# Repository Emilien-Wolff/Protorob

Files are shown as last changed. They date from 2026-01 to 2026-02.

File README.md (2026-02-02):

# Protorob – Robot thermomètre à affichage analogique 🤖
> [!NOTE]
> Projet réalisé dans le cadre de l’UE *Prototypage des systèmes robotisés* visant la conception et la réalisation complète d’un robot thermomètre asservi en position.

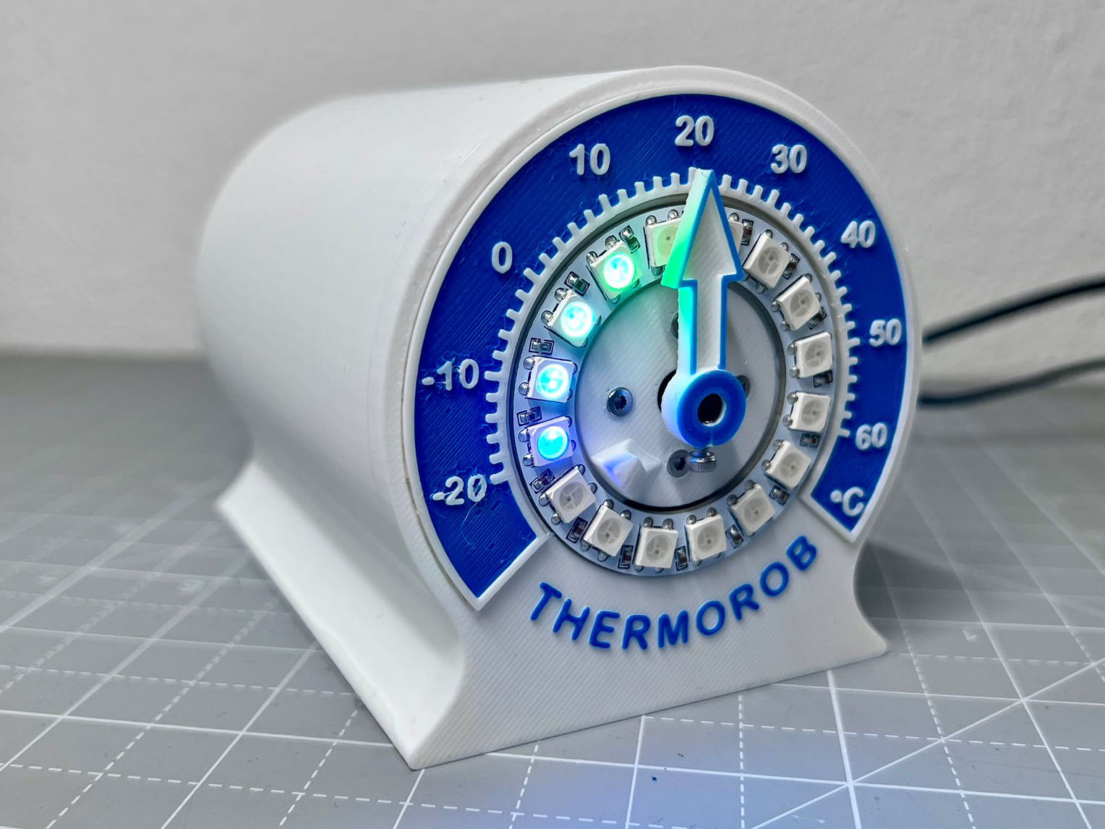
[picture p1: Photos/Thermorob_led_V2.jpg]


## Objectifs

> Mesurer une température à l’aide d’un capteur dédié et l’afficher physiquement via une aiguille entraînée par un moteur

> Mettre en œuvre un asservissement en position précis et stable par l’implémentation d’un régulateur PID discret sur microcontrôleur

## Points abordés

- Gestion de projet sur un temps court (3 semaines) avec planification des tâches et travail en autonomie sur des créneaux dédiés  
- Conception d’un système volontairement simple dans son principe, mais nécessitant une implémentation rigoureuse et propre  
- Lecture de la température via un capteur **MPL3115A2** et communication **I2C**  
- Implémentation d’un **régulateur PID monovariable** avec gestion du pas d’échantillonnage  
- Codage du régulateur à l’aide d’un **timer matériel** et de **routines d’interruption** sous Arduino  
- Conception mécanique complète du robot thermomètre, de l’aiguille et du support moteur  
- Réalisation de la **CAO 3D intégrale sous Fusion 360**  
- Tests, réglages expérimentaux et validation du comportement du système  
- Communication et coordination au sein d’un groupe de 4 personnes

## Compétences mobilisées

- Programmation embarquée (Arduino, C/C++)
- Automatique : régulation PID discrète
- Gestion du temps réel (timer, interruptions)
- Prototypage mécanique et CAO 3D
- Tests, réglages et validation expérimentale
- Travail en équipe et gestion de projet court

*📄 Le rapport complet du projet, détaillant la conception, l’implémentation et les choix techniques, est disponible à la racine du dépôt (`main`).*

## FAQ

#### Quel est l'intérêt de ce robot ?
Evidemment, ce type de mesure de température n'est pas voire pas du tout le plus répandu, mais il s'avère que le projet était l'occasion à tout le monde de découvrir le prototypage à travers 3 fondamentaux : l'électronique et la programmation, la conception mécanique et le contrôle commande. Nous nous sommes appropriés le sujet en faisant notre propre version du robot.

#### Combien de temps ça vous a pris ?

Le projet s’est déroulé sur **3 semaines**, avec des créneaux dédiés, depuis la phase de conception jusqu’aux tests et à la soutenance finale.

## 🚀 Qui sommes-nous ?
Nous sommes actuellement étudiants en école d’ingénieur à **IMT Atlantique**, et ce projet s’inscrit dans notre formation en **automatique et systèmes cyber-physiques**. Merci à Loïc Fournier, Grégory Boursin et Cédric Léger pour le travail.

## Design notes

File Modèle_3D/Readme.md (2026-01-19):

# Modèle 3D – Robot Thermomètre Protorob

Ce dossier contient l’ensemble des **fichiers de conception mécanique** du robot thermomètre réalisé dans le cadre du projet **Protorob**.

La conception a été réalisée **entièrement sous Fusion 360**, puis exportée en fichiers **STL** pour l’impression 3D.
Impression 3D en PLA sur P1S, 0,2mm d'épaisseur de couche, avec supports

---

## 📂 Contenu du dossier

### 🔧 Fichiers de conception
- `Conception Protorob.f3z`  
  → Fichier **Fusion 360** contenant l’assemblage complet et l’historique de conception

### 🖨️ Fichiers pour impression 3D
- `Cadran V3.stl`  
  → Cadran gradué pour l’affichage de la température  
- `Flèche.stl`  
  → Aiguille entraînée par le moteur  
- `boitier V3.stl`  
  → Boîtier principal du robot thermomètre  
- `plaque arrière.stl`  
  → Plaque arrière de fermeture et de maintien des composants

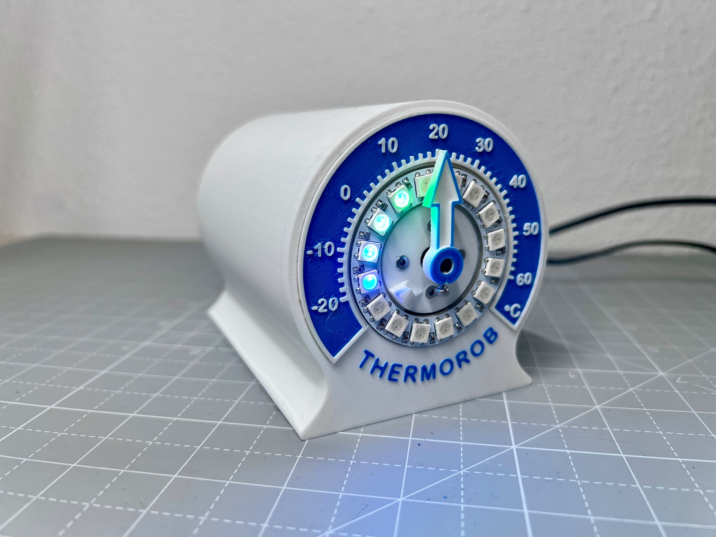
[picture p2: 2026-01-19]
Photos/Thermorob_led.jpeg

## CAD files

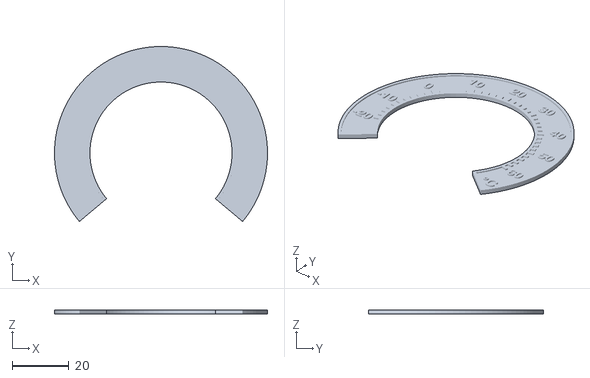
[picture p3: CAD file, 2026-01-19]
Modèle_3D/Cadran V3.stl
75.0 x 61.6 x 1.50

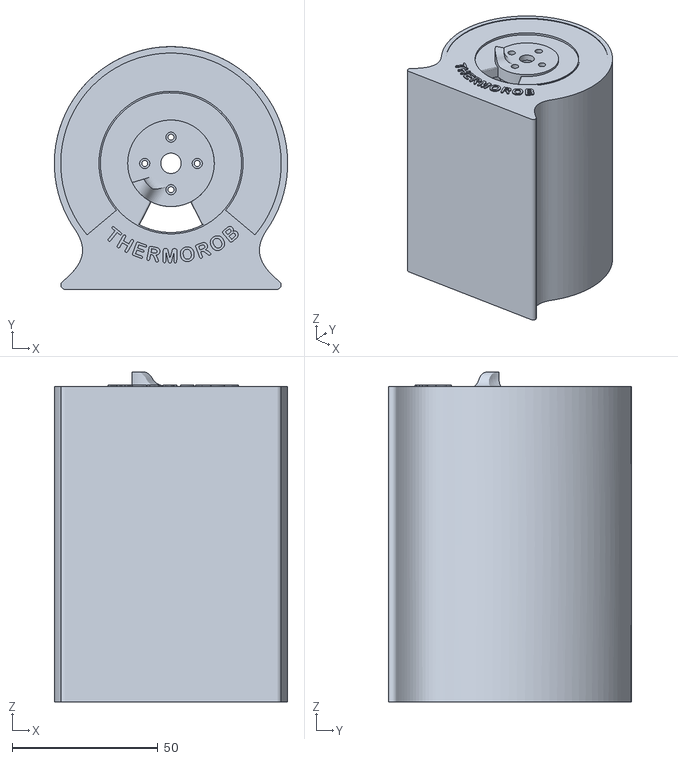
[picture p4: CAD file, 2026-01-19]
Modèle_3D/boitier V3.stl
80.0 x 83.2 x 113.1

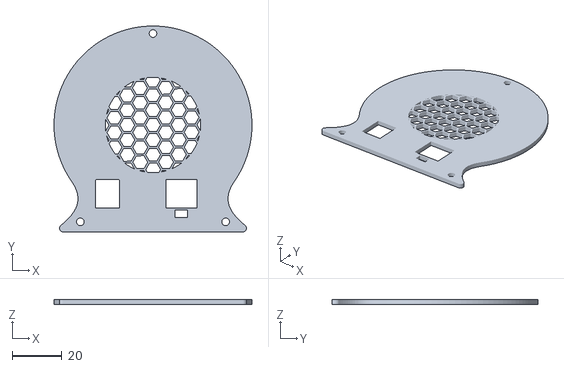
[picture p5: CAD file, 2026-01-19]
Modèle_3D/plaque arrière.stl
80.0 x 83.2 x 2.00

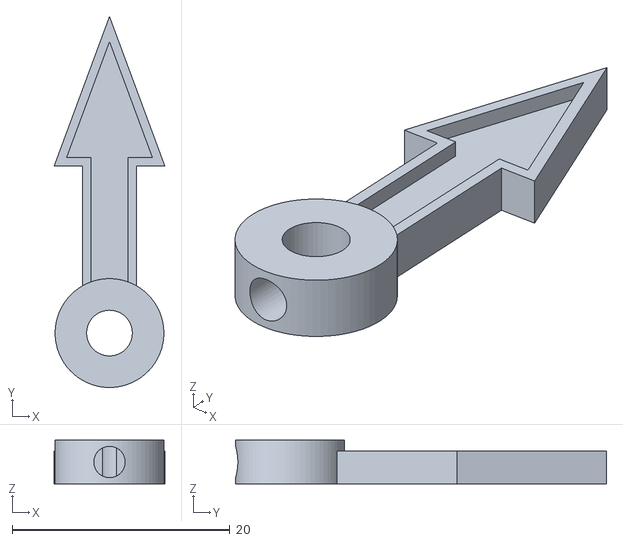
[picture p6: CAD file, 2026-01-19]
Modèle_3D/Flèche.stl
10.2 x 34.1 x 4.00

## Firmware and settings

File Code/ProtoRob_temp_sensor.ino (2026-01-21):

#include <Wire.h>
#include <Adafruit_MPL3115A2.h>
#include <Encoder.h>
#include <RunningMedian.h>
#include <FastLED.h>

// ================== PINS ==================
#define PIN_PWM 9
#define PIN_DIR 7
#define ENC_A   2
#define ENC_B   3

#define LED_PIN        6
#define NUM_LEDS_TOTAL 16    // LEDs physiques
#define NUM_LEDS_TEMP   10    // affichage temperature
#define LED_TYPE       WS2812B
#define COLOR_ORDER    GRB
#define LED_OFFSET     3     // decalage horaire

CRGB leds[NUM_LEDS_TOTAL];

// ================== SYSTEME MECANIQUE ==================
#define ENCODER_PPR     12    // nb de fentes dans l'encodeur par tour
#define QUAD_FACTOR     3     // fronts montants et descendants
#define GEAR_RATIO      19.0
#define NEEDLE_DEG      210.0 // amplitude en ° entre la position max et min

#define TICKS_PER_MOTOR_REV   (ENCODER_PPR * QUAD_FACTOR)
#define TICKS_PER_OUTPUT_REV  (TICKS_PER_MOTOR_REV * GEAR_RATIO)
#define TICKS_MAX (long)(TICKS_PER_OUTPUT_REV * (NEEDLE_DEG / 360.0))
#define OFFSET          -6    //TICKS

// ================== TEMP ==================
#define TEMP_LIMIT_MIN -20.0
#define TEMP_MAX 60.0

// ================== OBJETS ==================
Adafruit_MPL3115A2 tempSensor;
Encoder encoder(ENC_A, ENC_B);
RunningMedian samples(10);

// ================== PID ==================
volatile float Kp = 0.03; //2.0;
volatile float Ki = 0.004; //0.006;
volatile float Kd = 0.01; //10.0;   //impact du Kd négligeable

volatile long targetPosition = 0;
volatile long currentPosition = 0;

volatile float error = 0;
volatile float prevError = 0;
volatile float integral = 0;
volatile float output = 0;

volatile float error_isr = 0;
volatile float output_isr = 0;

#define PWM_MAX 255
#define PWM_MIN 60          // vitesse minimale pour garantir la rotation
#define INTEGRAL_LIMIT 2000

// ================== ROUTINE D'INTERRUPTION (200 Hz) ==================
ISR(TIMER1_COMPA_vect) {

  currentPosition = -encoder.read();
  error = targetPosition - currentPosition;

  integral += error;
  integral = constrain(integral, -INTEGRAL_LIMIT, INTEGRAL_LIMIT);  // partie integrale bornee

  float derivative = error - prevError;                     // calcul de variation de l'erreur
  prevError = error;

  output = Kp * error + Ki * integral + Kd * derivative;    // calcul du PID
  output = constrain(output, -PWM_MAX, PWM_MAX);            // sortie bornee

  error_isr  = error;
  output_isr = output;

  if (abs(error) < 2) {
    analogWrite(PIN_PWM, 0);       // si l'erreur de position est suffisemment faible, on arrete le moteur
  } else {
    int pwm = abs(output);
    pwm = constrain(pwm, PWM_MIN, PWM_MAX);

    digitalWrite(PIN_DIR, (error > 0) ? LOW : HIGH);  // si l'erreur est positive, on tourne dans un sens
    analogWrite(PIN_PWM, pwm);                        // sinon dans l'autre
  }
}

// ================== LED CALIBRATION ==================
void blinkCalibrationLeds(bool state) {             // fait clignoter les leds en orange durant la calibration
  CRGB color = state ? CRGB::Orange : CRGB::Black;
  for (int i = 0; i < NUM_LEDS_TOTAL; i++) {
    leds[i] = color;
  }
  FastLED.show();
}

// ================== CALIBRATION ==================
void calibrateNeedle() {

  Serial.println("=== CALIBRATION EN COURS ===");

  long lastPosition = encoder.read();
  long current;
  int stableCount = 0;
  bool ledState = false;
  unsigned long lastBlink = 0;

  digitalWrite(PIN_DIR, HIGH);      // on fait tourner l'aiguille vers la gauche pour aller sur la butee

  analogWrite(PIN_PWM, 60);             // on lance le moteur à la vitesse min normale
  delay(130);
  analogWrite(PIN_PWM, 30);             // on diminue pour se mettre au plus lent et ne pas casser la butee

  while (stableCount < 3) {

    if (millis() - lastBlink > 250) {   // on change l'etat des leds toutes les 250ms
      lastBlink = millis();
      ledState = !ledState;
      blinkCalibrationLeds(ledState);
    }

    delay(20);
    current = encoder.read();
    long delta = abs(current - lastPosition);
    lastPosition = current;

    if (delta <= 1) stableCount++;      // l'aiguille est bloquee 3 fois de suite pour sortir de la boucle while
    else stableCount = 0;
  }

  analogWrite(PIN_PWM, 0);              // arret du moteur
  encoder.write(0 + OFFSET);            // initialisation du codeur

  FastLED.clear();                      // on eteint les leds
  FastLED.show();                       // application du clear

  integral = 0;
  prevError = 0;
  targetPosition = 0;

  Serial.println("=== CALIBRATION OK ===");
}

// ================== LED TEMPERATURE ==================
void updateTemperatureRing(float temperature) {

  temperature = constrain(temperature, TEMP_LIMIT_MIN, TEMP_MAX);

  int activeLeds = map(
    (int)temperature,
    (int)TEMP_LIMIT_MIN,
    (int)TEMP_MAX,
    1,
    NUM_LEDS_TEMP
  );
  activeLeds = constrain(activeLeds, 1, NUM_LEDS_TEMP);

  FastLED.clear();

  // --- ALLUMAGE DU DÉGRADÉ ---
  for (int i = 0; i < activeLeds; i++) {

    int ledIndex = (LED_OFFSET + i) % NUM_LEDS_TOTAL;

    uint8_t hue = map(i, 0, NUM_LEDS_TEMP - 1, 160, 0); // bleu → rouge
    leds[ledIndex] = CHSV(hue, 255, 255);
  }

  // --- EXTINCTION DES 6 LEDS RESTANTES (ANTI-HORAIRE) ---
  for (int i = NUM_LEDS_TEMP; i < NUM_LEDS_TOTAL; i++) {
    int ledIndex = (LED_OFFSET + i) % NUM_LEDS_TOTAL;
    leds[ledIndex] = CRGB::Black;
  }

  FastLED.show();
}

// ================== TIMER SETUP ==================
void setupTimer1() {                     // setup timer 1 : 16 bits
  cli();                                 // désactive l'interruption globale
  TCCR1A = 0;                            // registres de controle
  TCCR1B = 0;
  OCR1A = 1249;                          // comparaison des sorties sur timer 1
  TCCR1B |= (1 << WGM12);                // activation du mode CTC
  TCCR1B |= (1 << CS11) | (1 << CS10);   // reglage du prescaler
  TIMSK1 |= (1 << OCIE1A);               // flag d'interruption
  sei();                                 // mise en route des interruptions
}

// ================== SETUP ==================
void setup() {

  Serial.begin(115200);
  Wire.begin();

  pinMode(PIN_PWM, OUTPUT);           // pins de controle du pont en H
  pinMode(PIN_DIR, OUTPUT);

  FastLED.addLeds<LED_TYPE, LED_PIN, COLOR_ORDER>(leds, NUM_LEDS_TOTAL);
  FastLED.setBrightness(10);          // gestion de la luminosite des leds
  FastLED.clear();
  FastLED.show();

  if (!tempSensor.begin()) {          // initialisation de la com avec le capteur de temp
    Serial.println("ERREUR CAPTEUR !");
    while (1);
  }

  calibrateNeedle();                  // recherche de la butee
  setupTimer1();                      // demarrage du timer
}

// ================== LOOP ==================
void loop() {

  float temp = tempSensor.getTemperature(); // mesure de la temperature
  samples.add(temp);                        // stockage dans la variable du PID

  float temperature = samples.getMedian();  // lissage pour eviter les glitchs
  temperature = constrain(temperature, TEMP_LIMIT_MIN, TEMP_MAX);

  targetPosition = map(       // definition des correspondances entre deux intervalles
    (int)temperature,
    (int)TEMP_LIMIT_MIN,      // intervalle de temperatures
    (int)TEMP_MAX,
    0,                        // intervalle des angles
    TICKS_MAX
  );
  targetPosition = constrain(targetPosition, 0, TICKS_MAX); // limitation dans un intervalle realiste
                                                            // par securite materielle
  updateTemperatureRing(temperature);                       // allumage des leds correspondantes

  // ---------- PRINT TEMP TOUTES LES 2 SECONDES ----------
  static unsigned long lastPrint = 0;

  if (millis() - lastPrint >= 2000) {                      // affichage de debug sur console Arduino
    lastPrint = millis();
    Serial.print("Température mesurée : ");
    Serial.print(temperature);
    Serial.println(" °C");
  }
  // -----------------------------------------------------

  delay(50);
}
